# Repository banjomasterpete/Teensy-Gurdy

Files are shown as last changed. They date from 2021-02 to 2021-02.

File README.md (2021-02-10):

# Teensy-Gurdy
Code and design files for building your own hurdy gurdy-inspired, Teensy-powered synthesizer!

Update: I've been having a few problems off and on with the sensitivity of the touch plates. If yours isn't working correctly unless you touch a ground, this should help. Go into the .cpp file for the Adafruit MPR121 library and uncomment the line where it says 'uncomment here to use autoconfig.' 

Howdy friends, here's the code I'm currently running in the Teensy Gurdy video with some added comments and the STL's for the case. 
I didn't initially intend for others to be looking at this so some details are going to be hazy, 
I highly suggest you watch the Notes and Volts Teensy synthesizer series as I learned how to build this project from watching my old pal Dave. The schematic is also the same as his TS-1 project with the addition of connecting the MPR121 to the Teensy I2C pins

Here's a parts list for the project:

15x 10kA potentiometers

2x SPDT switches

1x encoder (I used this one: https://www.ebay.com/itm/Rotary-Encoder-1000P-R-Incremental-Optical-Shaft-Working-Measurement-DC-5-24V-US/233759257400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)

12x conductive surfaces (I used custom PCB's but you can use lots of things. Adafruit's page has some suggestions about what works best)

1x Adafruit MPR121 breakout board

1x Teensy 3.2

1x Teensy 3.x Audio Shield (Not strictly necessary unless you want stereo audio but you will need to redo some code to use the 3.2's built in DAC if you don't want this)

1x CD4067/ 74HC4067 multiplexer chip

1x 5V regulator (Use something suitable like a 7805 and power it per the datasheet. I'm just a guy on the internet, don't blow up your Teensy!)

1x Some kinda way to get electricity to the regulator, a battery might be cool? The hole on the faceplate is sized for this type: https://www.ebay.com/itm/Panel-Mount-2-1mm-DC-barrel-jack/263111763480?hash=item3d42aee618:g:uKIAAOSwOg9ZeyIZ

1x Some kinda way to get audio out. The hole on the faceplate is sized for a 1/4" audio jack

1x USB connector. I didn't build one of these into mine but I wish I did

1x A knob, I pulled one off of a dresser but make sure you have at least one so you can get your clothes out

Resources that I used:
Notes and Volts: https://www.youtube.com/watch?v=UJcZxyB5rVc

Adafruit: https://learn.adafruit.com/adafruit-mpr121-12-key-capacitive-touch-sensor-breakout-tutorial

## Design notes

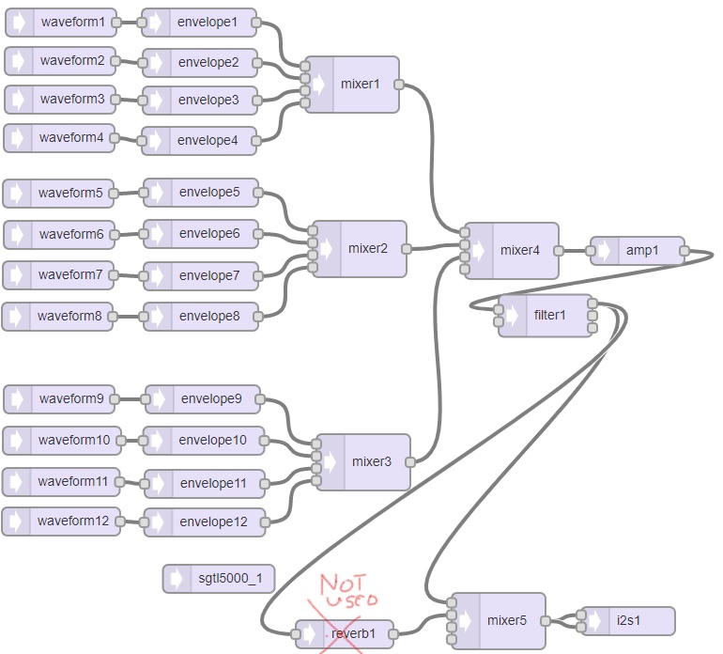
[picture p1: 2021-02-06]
InkedTeensy Gurdy Block DiagramV2_LI.jpg

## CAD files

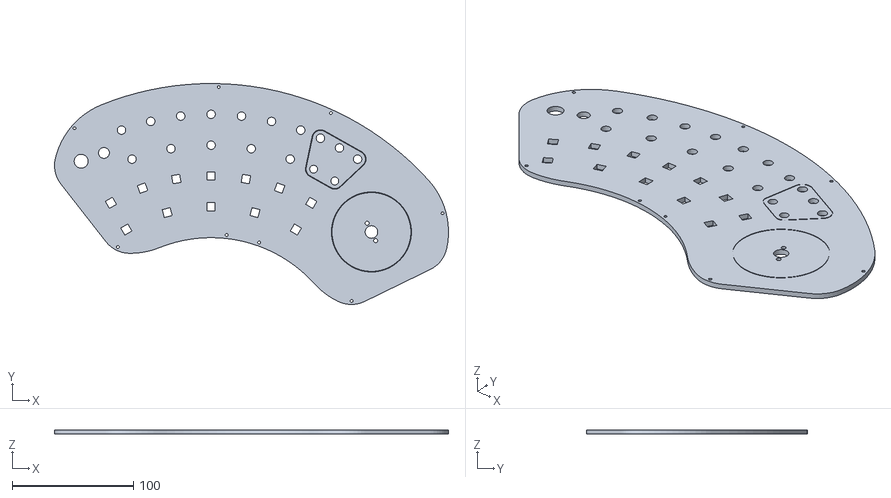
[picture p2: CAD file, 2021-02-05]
TeensyGurdyFaceplate.stl
324.7 x 182.0 x 3.60

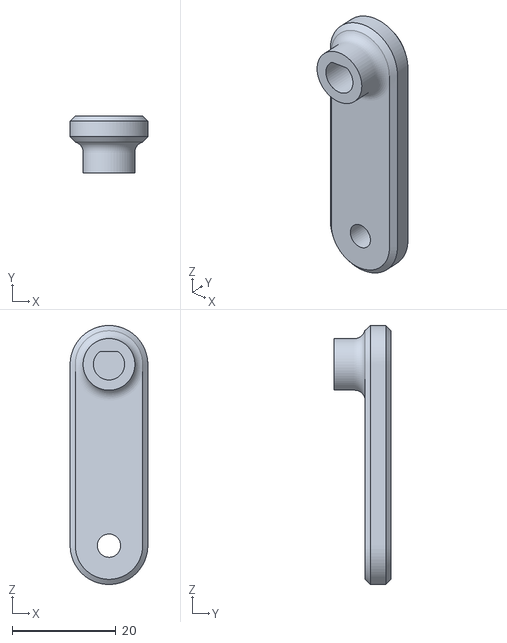
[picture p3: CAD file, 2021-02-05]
V2GurdyHandleEncoder.stl
15.0 x 11.0 x 50.0

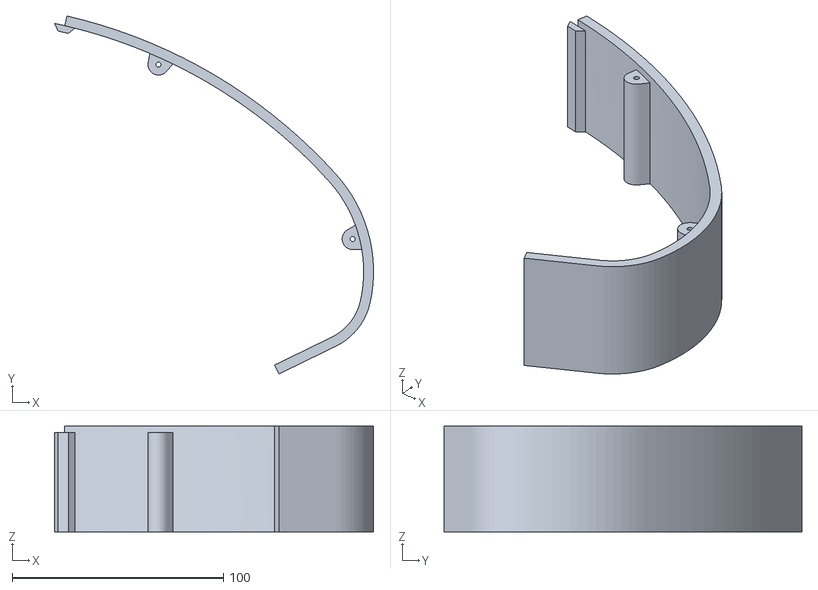
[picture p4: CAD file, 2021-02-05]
TeensyGurdySideC.stl
151.1 x 169.6 x 50.0

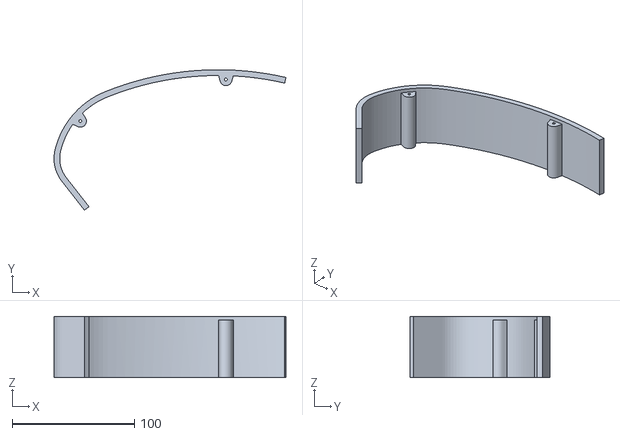
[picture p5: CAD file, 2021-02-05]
TeensyGurdySideA.stl
189.4 x 114.7 x 50.0

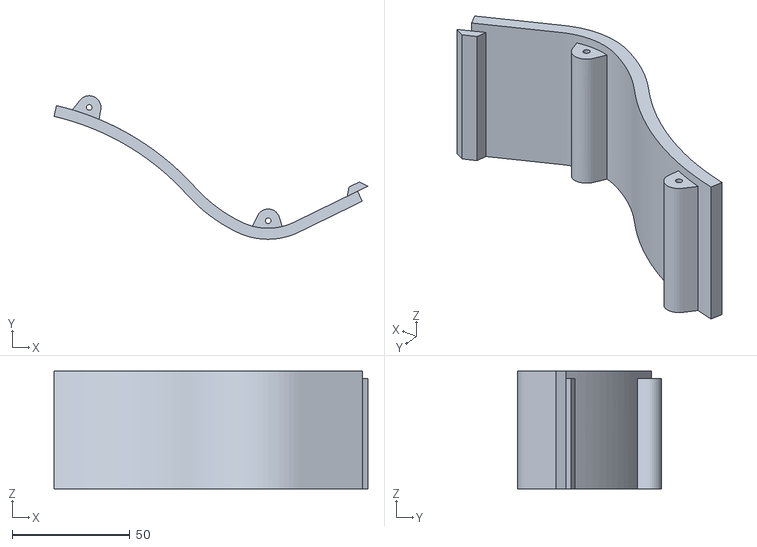
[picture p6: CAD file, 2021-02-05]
TeensyGurdySideB.stl
133.6 x 61.1 x 50.0

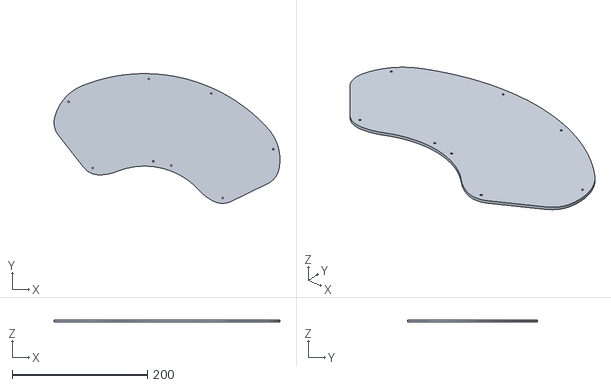
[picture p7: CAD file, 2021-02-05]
TeensyGurdyBackplate.stl
334.7 x 192.1 x 3.00

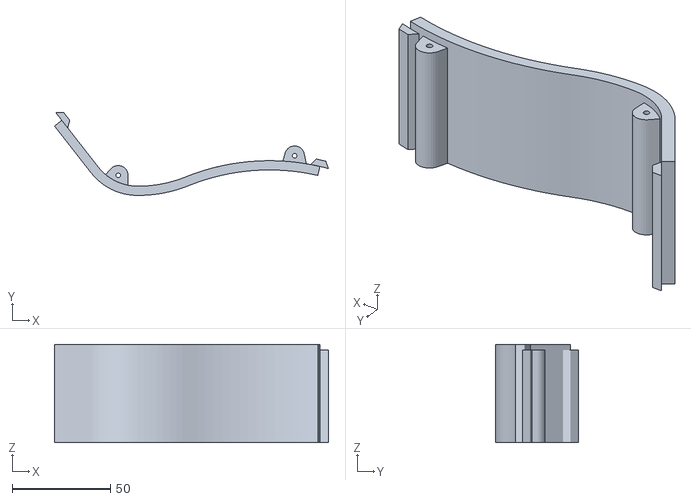
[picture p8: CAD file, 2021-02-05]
TeensyGurdySideD.stl
139.2 x 42.1 x 50.0

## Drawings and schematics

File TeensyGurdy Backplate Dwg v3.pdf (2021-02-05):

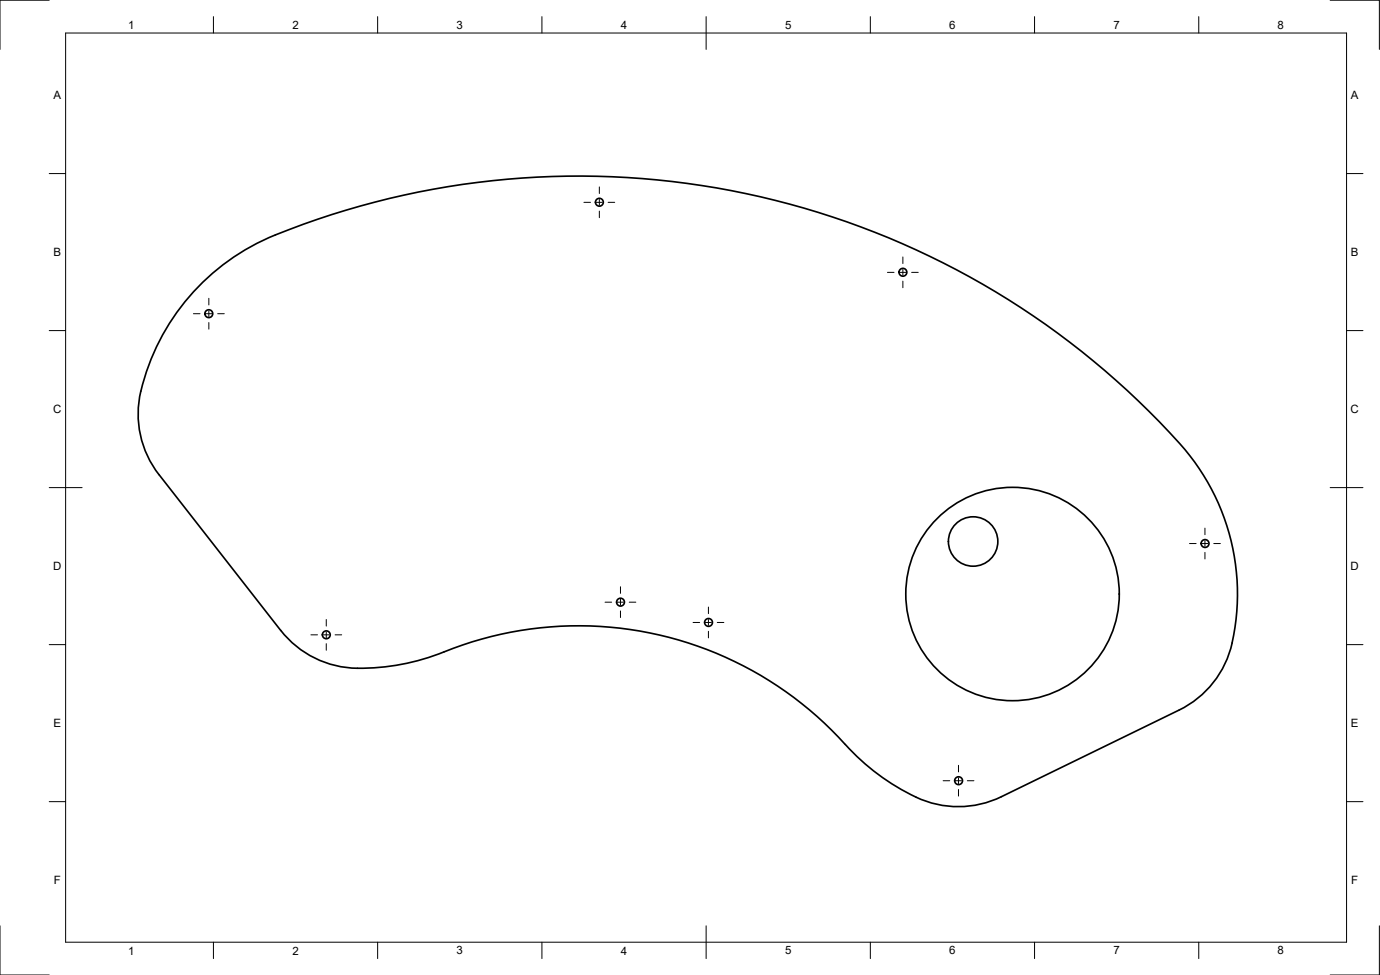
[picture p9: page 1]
8 BCDEF; ABCDEF

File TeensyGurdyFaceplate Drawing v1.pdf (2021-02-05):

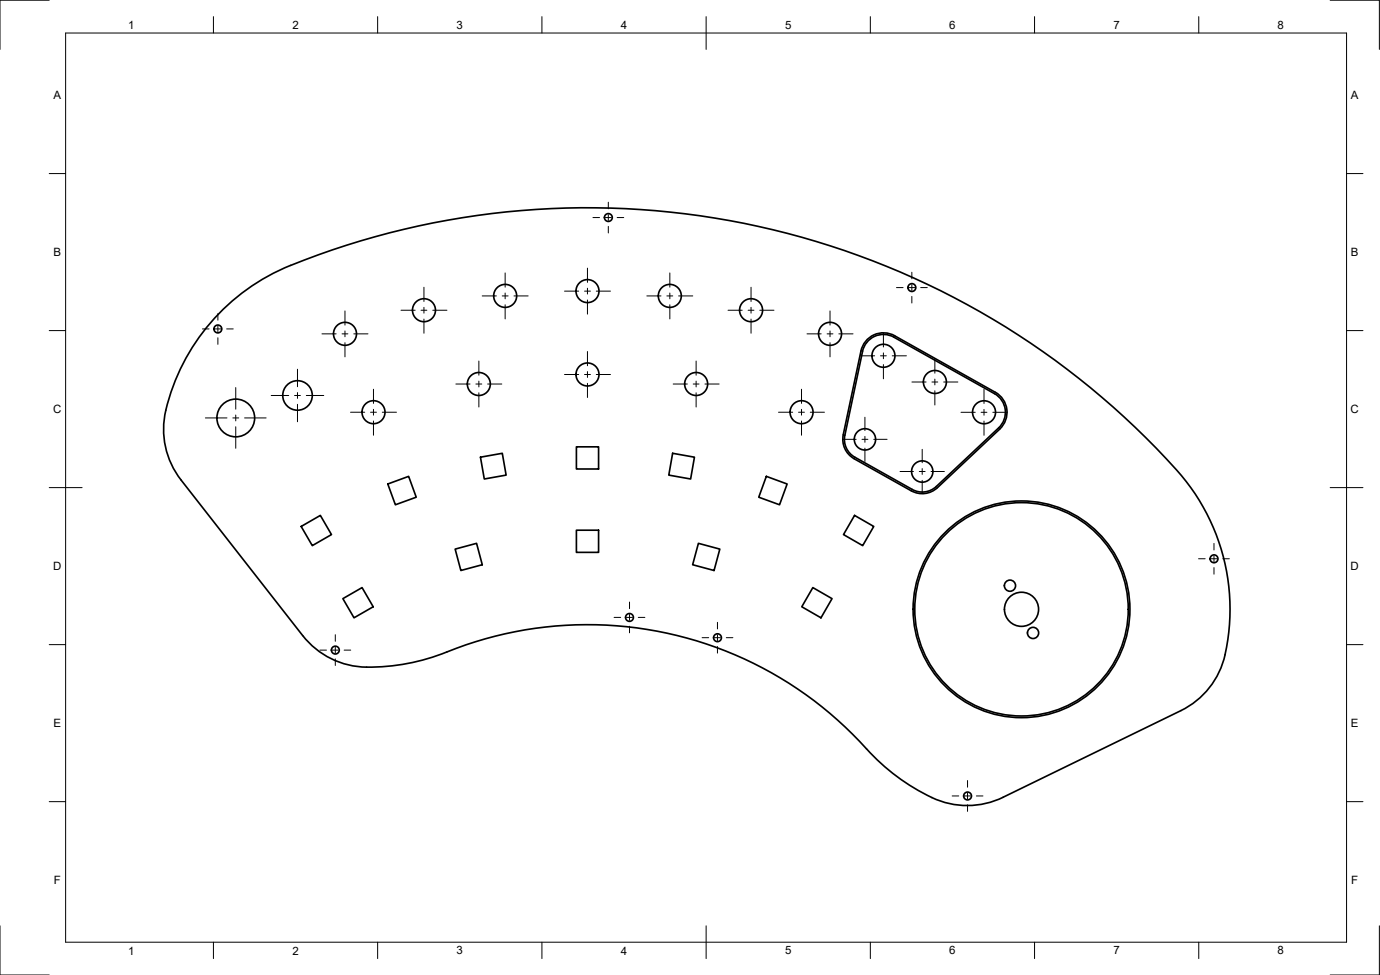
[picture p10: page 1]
8 BCDEF; ABCDEF

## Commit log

2021-02-04 Add files via upload
    This is the code I'm running in the Teensy Gurdy in the video with a few added comments to try and help folks understand what I'm doing. A lot of it is pulled from examples and other open source proj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
2021-02-06 Add files via upload
    This is a screenshot of the block diagram created in PJRC's audio system design tool. Check it out here: https://www.pjrc.com/teensy/gui/
2021-04-13 Add files via upload
    Upgraded the ADC resolution to 12 bit, changed the square waveform option to triangle waveform
